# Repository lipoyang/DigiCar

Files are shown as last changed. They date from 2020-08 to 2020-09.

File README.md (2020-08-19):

# DigiCar (デジカー)

## 概要
DigiCarは[RumiCar](https://www.rumicar.com/ja/top-page/)互換のミニ四駆サイズの自動運転カーです。

DigiCarは[デジもく会](https://dezimoku.connpass.com/)が企画しています。

## コンセプト
- [DigiCarのコンセプト](document/DigiCar_concept1.png)
- [DigiCarの回路設計概略](document/DigiCar_concept2.png)

## ハードウェア

- [回路図 (PDF)](hard/DigiCar.pdf)
- [CADデータ (Eagle)](hard/)　(※アートワークは未着手)

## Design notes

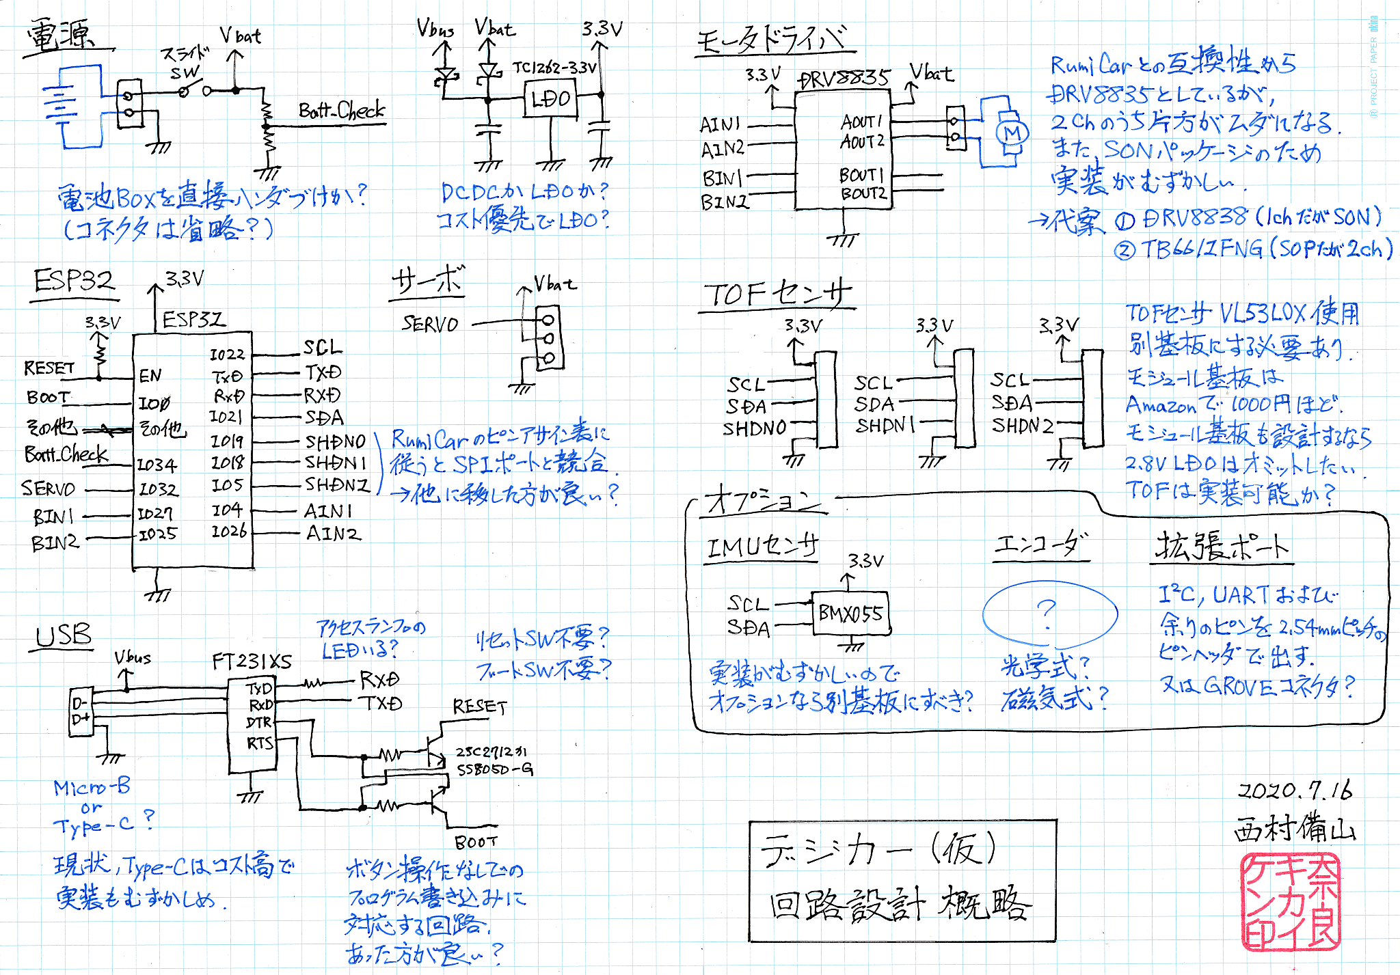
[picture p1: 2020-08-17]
document/DigiCar_concept2.png

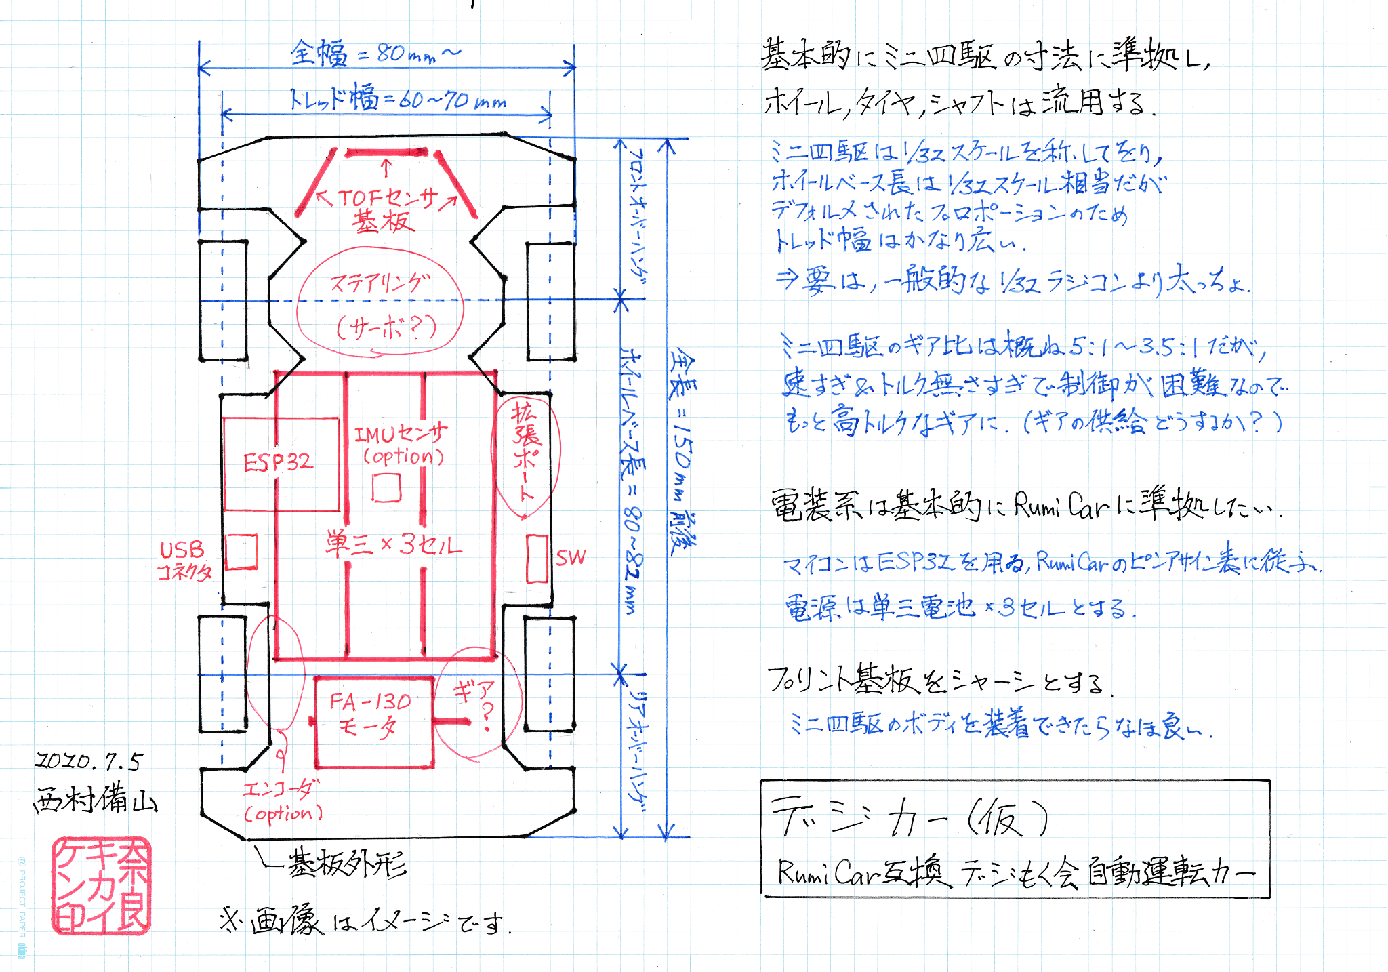
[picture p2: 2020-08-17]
document/DigiCar_concept1.png

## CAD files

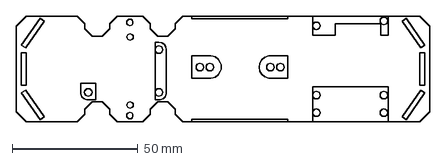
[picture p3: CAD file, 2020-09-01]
hard/outline.dxf
164.0 x 42.0 mm

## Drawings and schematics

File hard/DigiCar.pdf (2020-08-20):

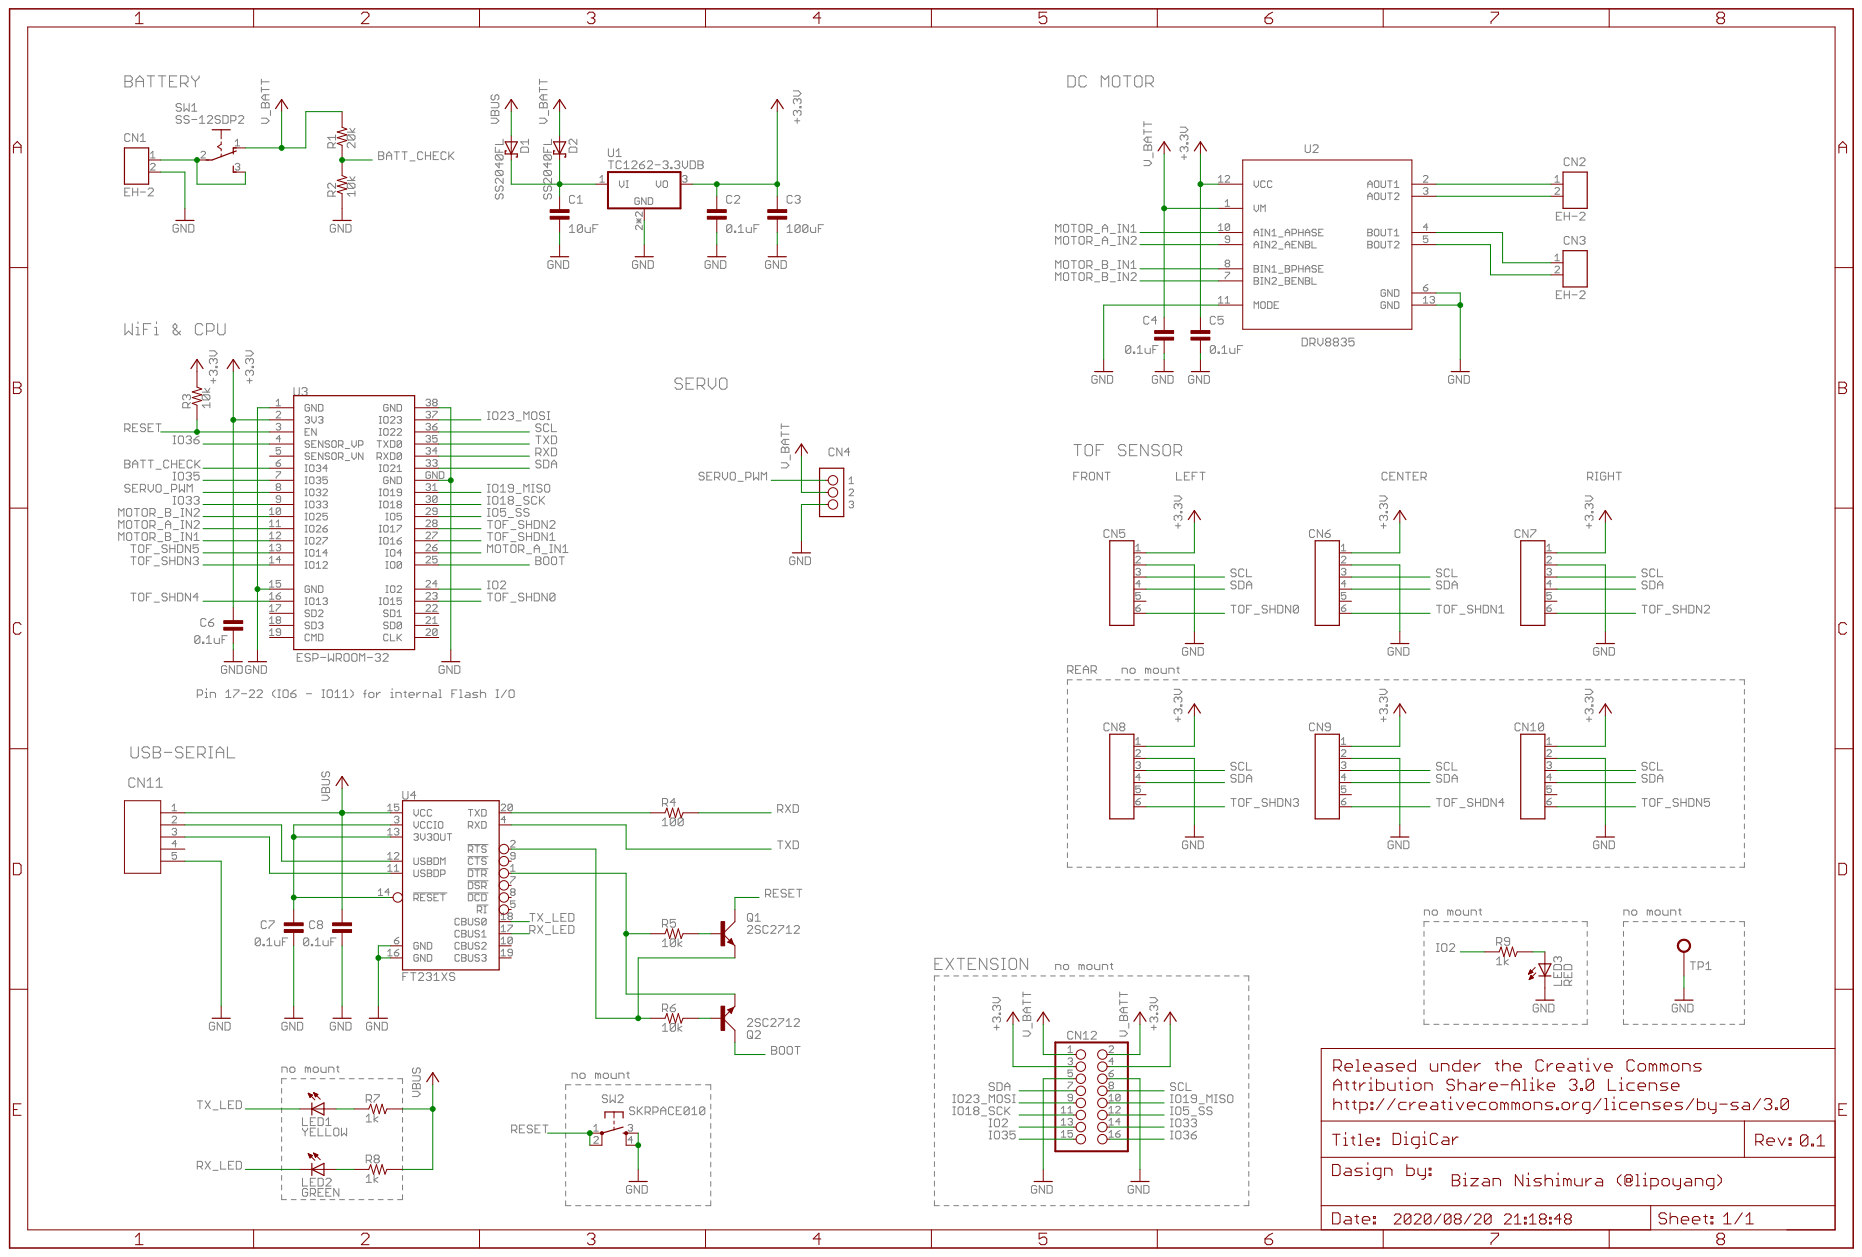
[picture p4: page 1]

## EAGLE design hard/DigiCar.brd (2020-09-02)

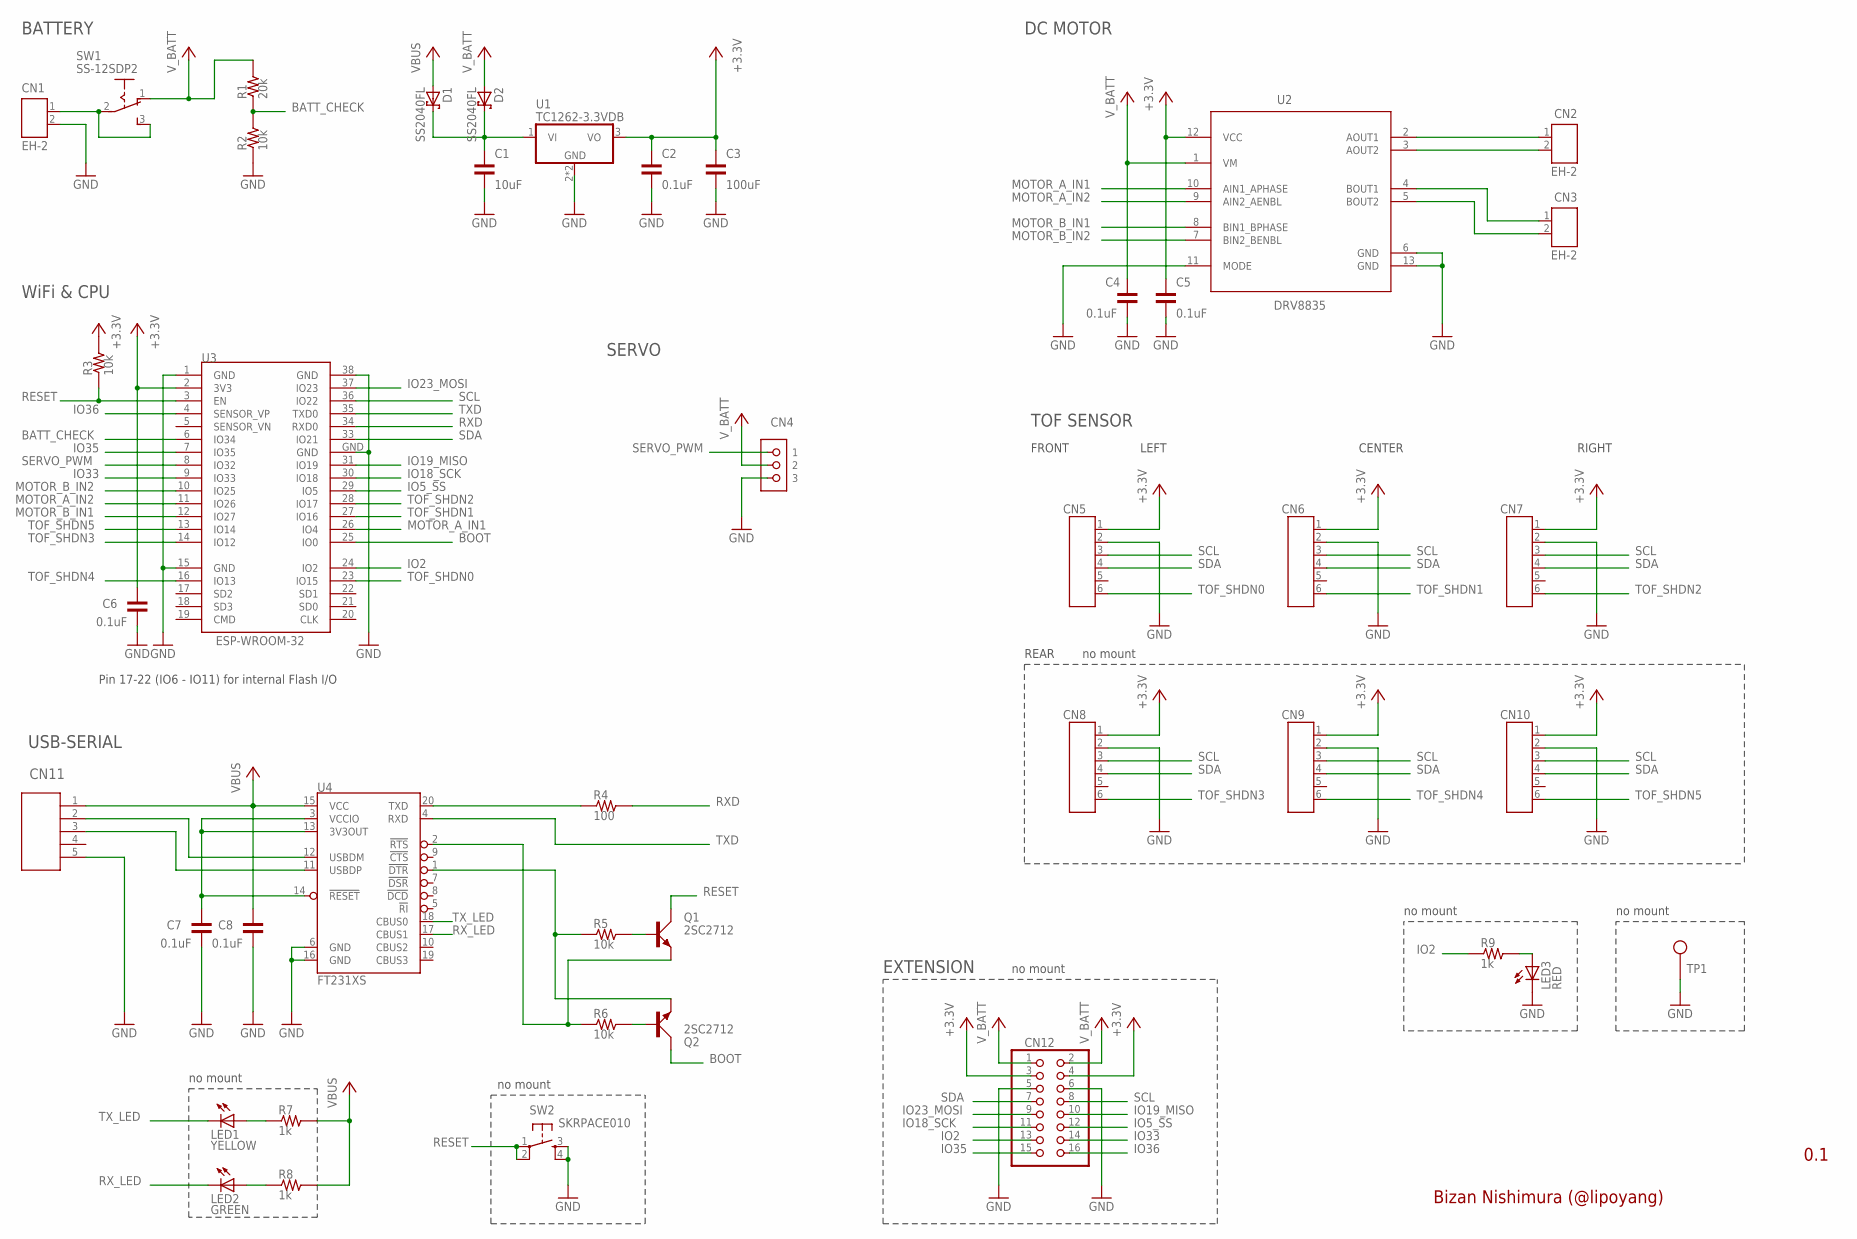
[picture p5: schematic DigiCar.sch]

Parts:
C1: 10uF; CP3216
C2, C4, C5, C6, C7, C8: 0.1uF; CP1608
C3: 100uF; CP3216
CN1, CN2, CN3: EH-2
CN4: PINHD-1X3; CON_RC_SERVO
CN5, CN6, CN7, CN8, CN9, CN10: PINHD-1X6; 1X06
CN11: ZX62-B-5PA(11); CONN_ZX62-B-5PA(11)_HIR
CN12: PINHD-2X8; 2X08
D1, D2: SS2040FL; SOD123
LED1: YELLOW; LED1608
LED2: GREEN; LED1608
LED3: RED; LED1608
Q1, Q2: 2SC2712; SC59
R1: 20k; CP1608
R2, R3, R5, R6: 10k; CP1608
R4: 100; CP1608
R7, R8, R9: 1k; CP1608
SW1: SS-12SDP2; SLIDE-SW
SW2: SKRPACE010
TP1: TEST_PIN
U1: TC1262-3.3VDB; SOT223
U2: DRV8835
U3: ESP-WROOM-32
U4: FT231XS; SSOP20

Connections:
+3V3: C2.SMD1 (PIN1), C3.SMD1 (PIN1), C5.SMD1 (PIN1), C6.SMD1 (PIN1), CN5.1, CN6.1, CN7.1, CN8.1, CN9.1, CN10.1, CN12.3, CN12.4, R3.SMD2 (PIN2), U1.3 (VO), U2.12 (VCC), U3.2 (3V3)
BATT_CHECK: R1.SMD1 (PIN1), R2.SMD2 (PIN2), U3.6 (IO34)
BOOT: Q2.C, U3.25 (IO0)
GND: C1.SMD2 (PIN2), C2.SMD2 (PIN2), C3.SMD2 (PIN2), C4.SMD2 (PIN2), C5.SMD2 (PIN2), C6.SMD2 (PIN2), C7.SMD2 (PIN2), C8.SMD2 (PIN2), CN1.2, CN4.3, CN5.2, CN6.2, CN7.2, CN8.2, CN9.2, CN10.2, CN11.5, CN12.5, CN12.6, LED3.C, R2.SMD1 (PIN1), SW2.3, SW2.4, TP1.1, U1.2 (GND), U1.4 (GND), U2.6 (GND), U2.11 (MODE), U2.13 (GND), U3.1 (GND), U3.15 (GND), U3.38 (GND), U3.GND, U4.6 (GND), U4.16 (GND)
IO2: CN12.13, R9.SMD1 (PIN1), U3.24 (IO2)
IO5_SS: CN12.12, U3.29 (IO5)
IO18_SCK: CN12.11, U3.30 (IO18)
IO19_MISO: CN12.10, U3.31 (IO19)
IO23_MOSI: CN12.9, U3.37 (IO23)
IO33: CN12.14, U3.9 (IO33)
IO35: CN12.15, U3.7 (IO35)
IO36: CN12.16, U3.4 (SENSOR_VP)
MOTOR_A_IN1: U2.10 (AIN1_APHASE), U3.26 (IO4)
MOTOR_A_IN2: U2.9 (AIN2_AENBL), U3.11 (IO26)
MOTOR_B_IN1: U2.8 (BIN1_BPHASE), U3.12 (IO27)
MOTOR_B_IN2: U2.7 (BIN2_BENBL), U3.10 (IO25)
unnamed: CN1.1, SW1.2, SW1.3 (S)
unnamed: LED3.A, R9.SMD2 (PIN2)
unnamed: C1.SMD1 (PIN1), D1.C, D2.C, U1.1 (VI)
unnamed: R4.SMD1 (PIN1), U4.20 (TXD)
unnamed: Q1.B, R5.SMD2 (PIN2)
unnamed: Q2.B, R6.SMD2 (PIN2)
unnamed: CN11.2, U4.12 (USBDM)
unnamed: CN11.3, U4.11 (USBDP)
unnamed: C7.SMD1 (PIN1), U4.3 (VCCIO), U4.13 (3V3OUT), U4.14 (!RESET)
unnamed: Q2.E, R5.SMD1 (PIN1), U4.1 (!DTR)
unnamed: Q1.E, R6.SMD1 (PIN1), U4.2 (!RTS)
unnamed: CN2.1, U2.2 (AOUT1)
unnamed: CN2.2, U2.3 (AOUT2)
unnamed: LED1.A, R7.SMD1 (PIN1)
unnamed: LED2.A, R8.SMD1 (PIN1)
unnamed: CN3.1, U2.4 (BOUT1)
unnamed: CN3.2, U2.5 (BOUT2)
RESET: Q1.C, R3.SMD1 (PIN1), SW2.1, SW2.2, U3.3 (EN)
RXD: R4.SMD2 (PIN2), U3.34 (RXD0)
RX_LED: LED2.C, U4.17 (CBUS1)
SCL: CN5.3, CN6.3, CN7.3, CN8.3, CN9.3, CN10.3, CN12.8, U3.36 (IO22)
SDA: CN5.4, CN6.4, CN7.4, CN8.4, CN9.4, CN10.4, CN12.7, U3.33 (IO21)
SERVO_PWM: CN4.1, U3.8 (IO32)
TOF_SHDN0: CN5.6, U3.23 (IO15)
TOF_SHDN1: CN6.6, U3.27 (IO16)
TOF_SHDN2: CN7.6, U3.28 (IO17)
TOF_SHDN3: CN8.6, U3.14 (IO12)
TOF_SHDN4: CN9.6, U3.16 (IO13)
TOF_SHDN5: CN10.6, U3.13 (IO14)
TXD: U3.35 (TXD0), U4.4 (RXD)
TX_LED: LED1.C, U4.18 (CBUS0)
VBUS: C8.SMD1 (PIN1), CN11.1, D1.A, R7.SMD2 (PIN2), R8.SMD2 (PIN2), U4.15 (VCC)
V_BATT: C4.SMD1 (PIN1), CN4.2, CN12.1, CN12.2, D2.A, R1.SMD2 (PIN2), SW1.1 (O), U2.1 (VM)

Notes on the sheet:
BATTERY
Bizan Nishimura (@lipoyang)
0.1
USB-SERIAL
DC MOTOR
WiFi & CPU
no mount
Pin 17-22 (IO6 - IO11) for internal Flash I/O
SERVO
TOF SENSOR
REAR
FRONT
LEFT
CENTER
RIGHT
EXTENSION

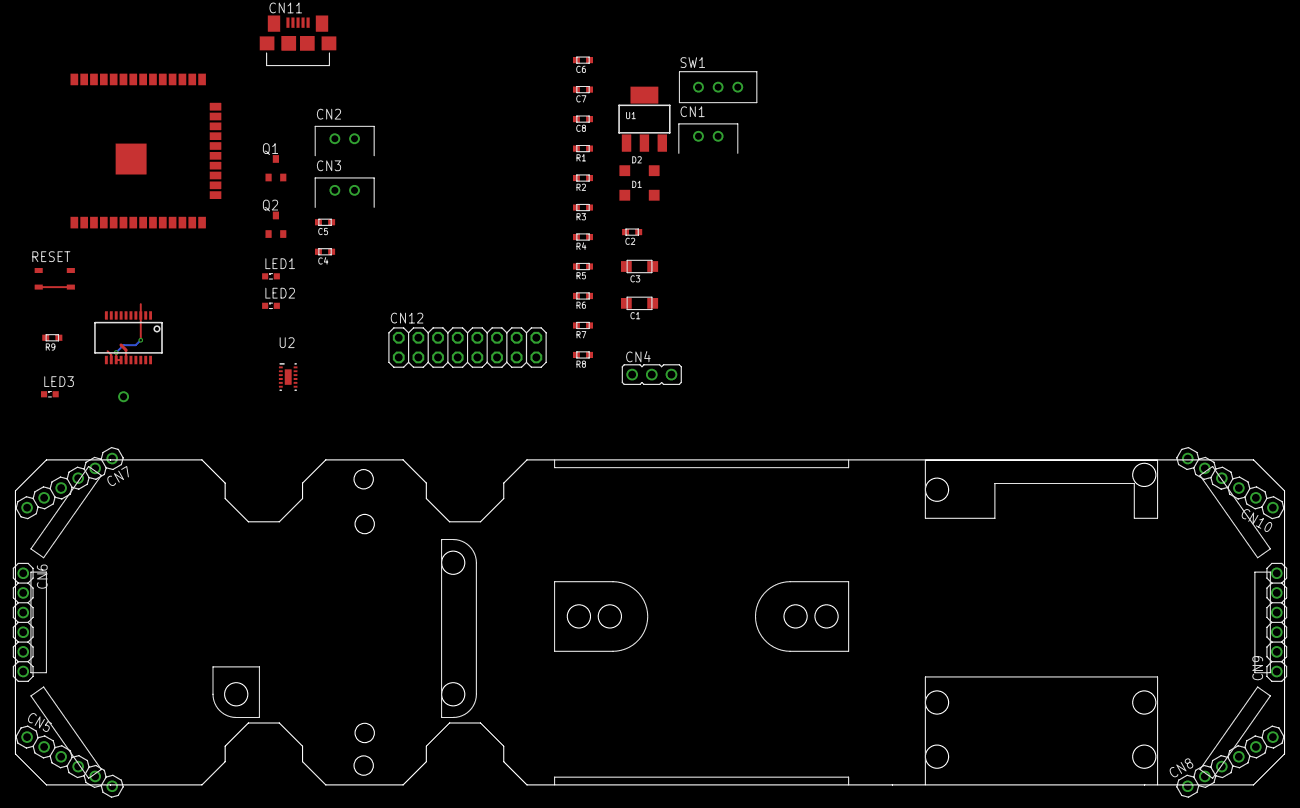
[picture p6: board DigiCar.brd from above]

Board: 2 copper layers, 164.0 x 42.0 mm, 43 parts (0 on the bottom side), 49 nets.

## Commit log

2020-08-19 CADデータを追加
    [DigiCar.brd, DigiCar.sch]
2020-08-19 READMEとCADデータを修正
    [DigiCar.brd]
2020-08-20 回路を修正
    [DigiCar.brd, DigiCar.sch]
2020-09-01 基板外形データを追加
    [outline.dxf]
2020-09-01 .gitignoreを修正
2020-09-01 ボードに基板外形を作図
    [DigiCar.brd]
2020-09-01 基板外形を修正
    [DigiCar.brd]
2020-09-02 ToFセンサを配置(仮)
    [DigiCar.brd]

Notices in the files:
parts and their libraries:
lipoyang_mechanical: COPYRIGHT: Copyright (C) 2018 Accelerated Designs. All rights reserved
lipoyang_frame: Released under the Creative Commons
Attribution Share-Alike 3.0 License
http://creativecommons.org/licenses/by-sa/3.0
